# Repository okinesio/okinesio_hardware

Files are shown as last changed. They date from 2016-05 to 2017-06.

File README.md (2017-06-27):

# okinesio | Hardware files

This repository contains resources for the okinesio boards.

Head over to [okinesio.org/hardware](http://okinesio.org/hardware) for an overview.

License Information
-------------------
The hardware designs are released under [CC-SA v3 license](http://creativecommons.org/licenses/by-sa/3.0).

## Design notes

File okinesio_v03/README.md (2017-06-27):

# okinesio v0.3

The latest version with completely new layout. Featuring an on-board lipo charger and lipo connector which replaces the coin cell.
With the BMM150 (magnetometer) the board is adding up to 9-DOF and there is a microSD card reader on the backside.

```
Size:    approx. 30 x 20 mm

Operating Voltage:     3.3V
Input Voltage:         3-5V
Clock Speed:           8MHz

Microcontroller: ATmega32U4
Flash:                32 KB
SRAM:                2.5 KB
EEPROM:                1 KB
```

Eagle files and schematics are modified and extended versions of the original files from [LilyPad Arduino USB](https://github.com/sparkfun/LilyPad_Arduino_USB).

License Information
-------------------
The hardware design is released under [CC-SA v3 license](http://creativecommons.org/licenses/by-sa/3.0).

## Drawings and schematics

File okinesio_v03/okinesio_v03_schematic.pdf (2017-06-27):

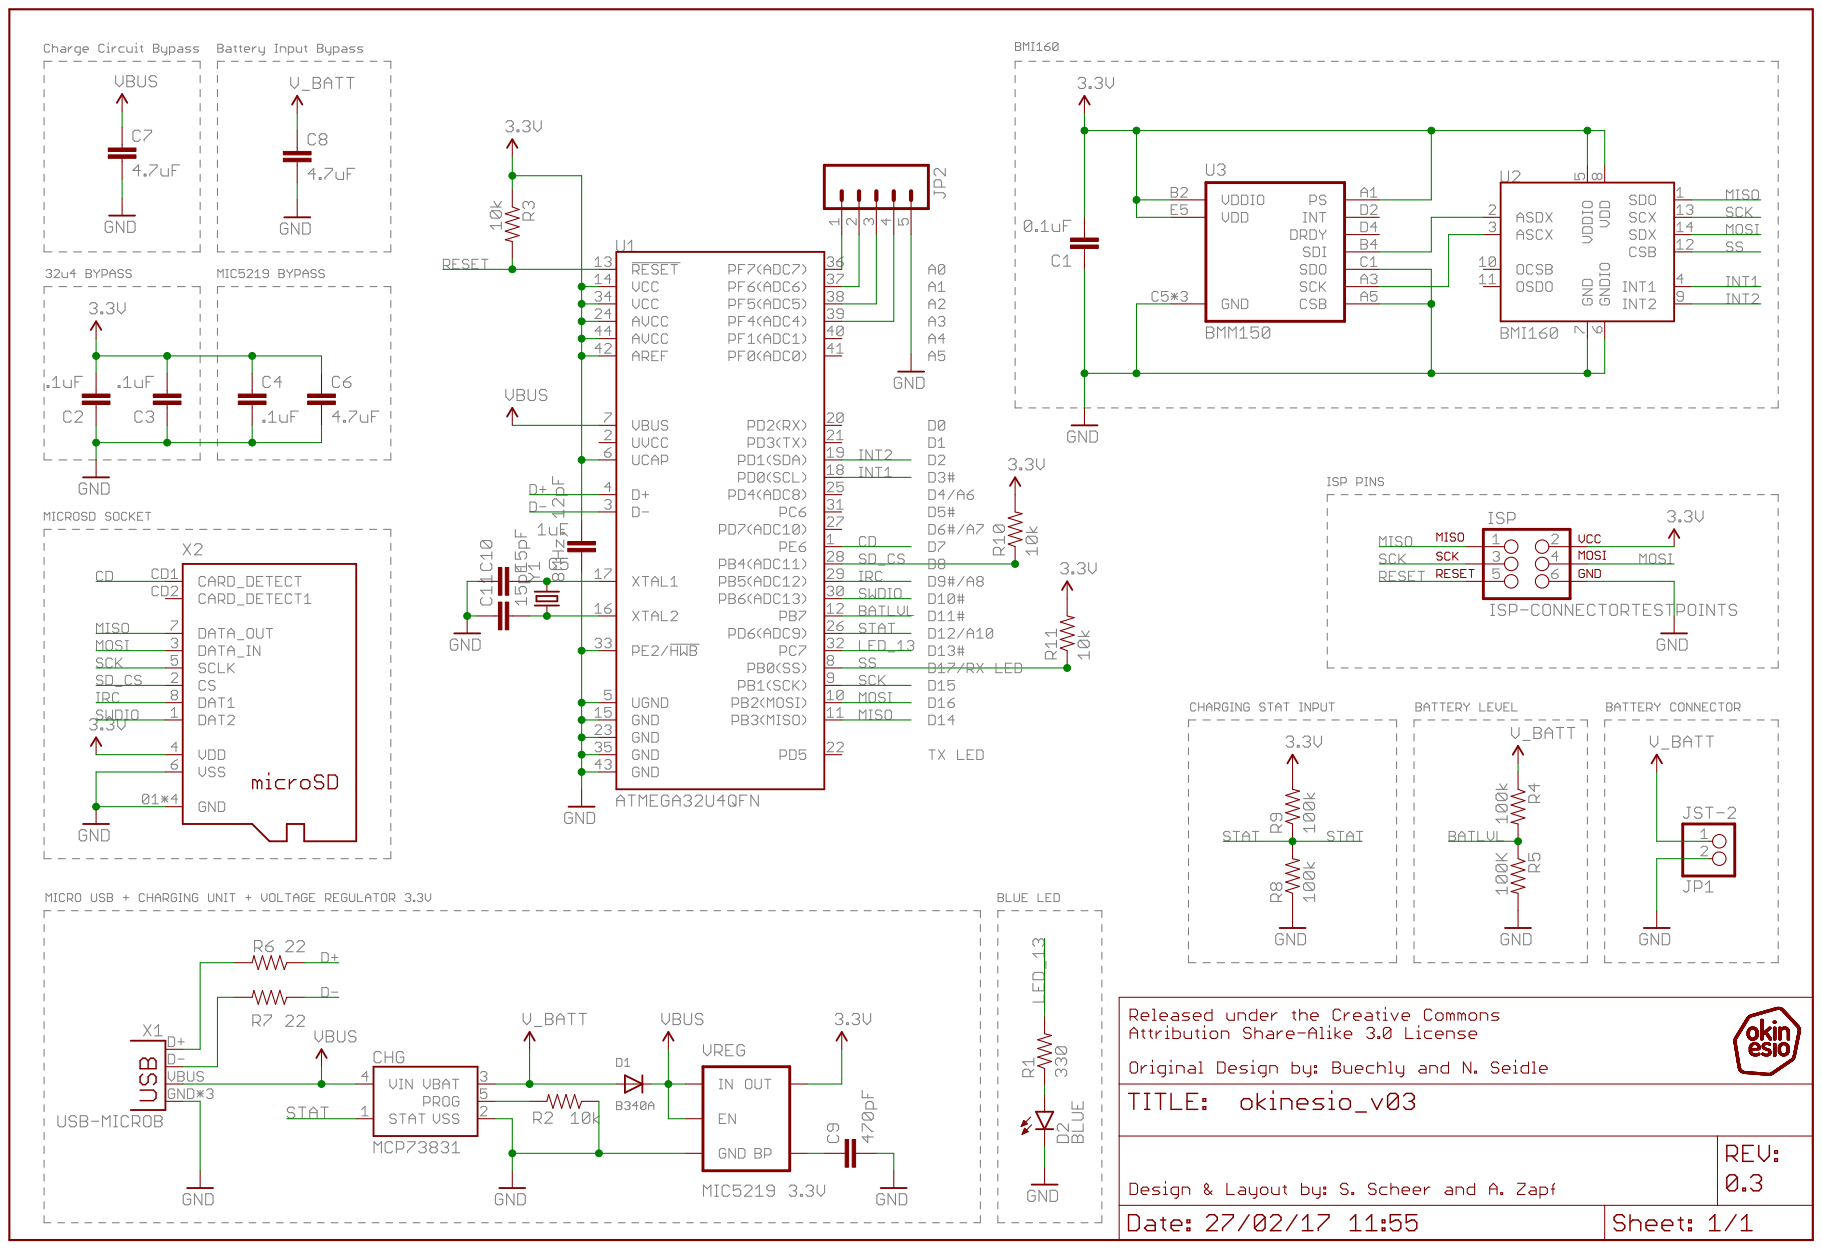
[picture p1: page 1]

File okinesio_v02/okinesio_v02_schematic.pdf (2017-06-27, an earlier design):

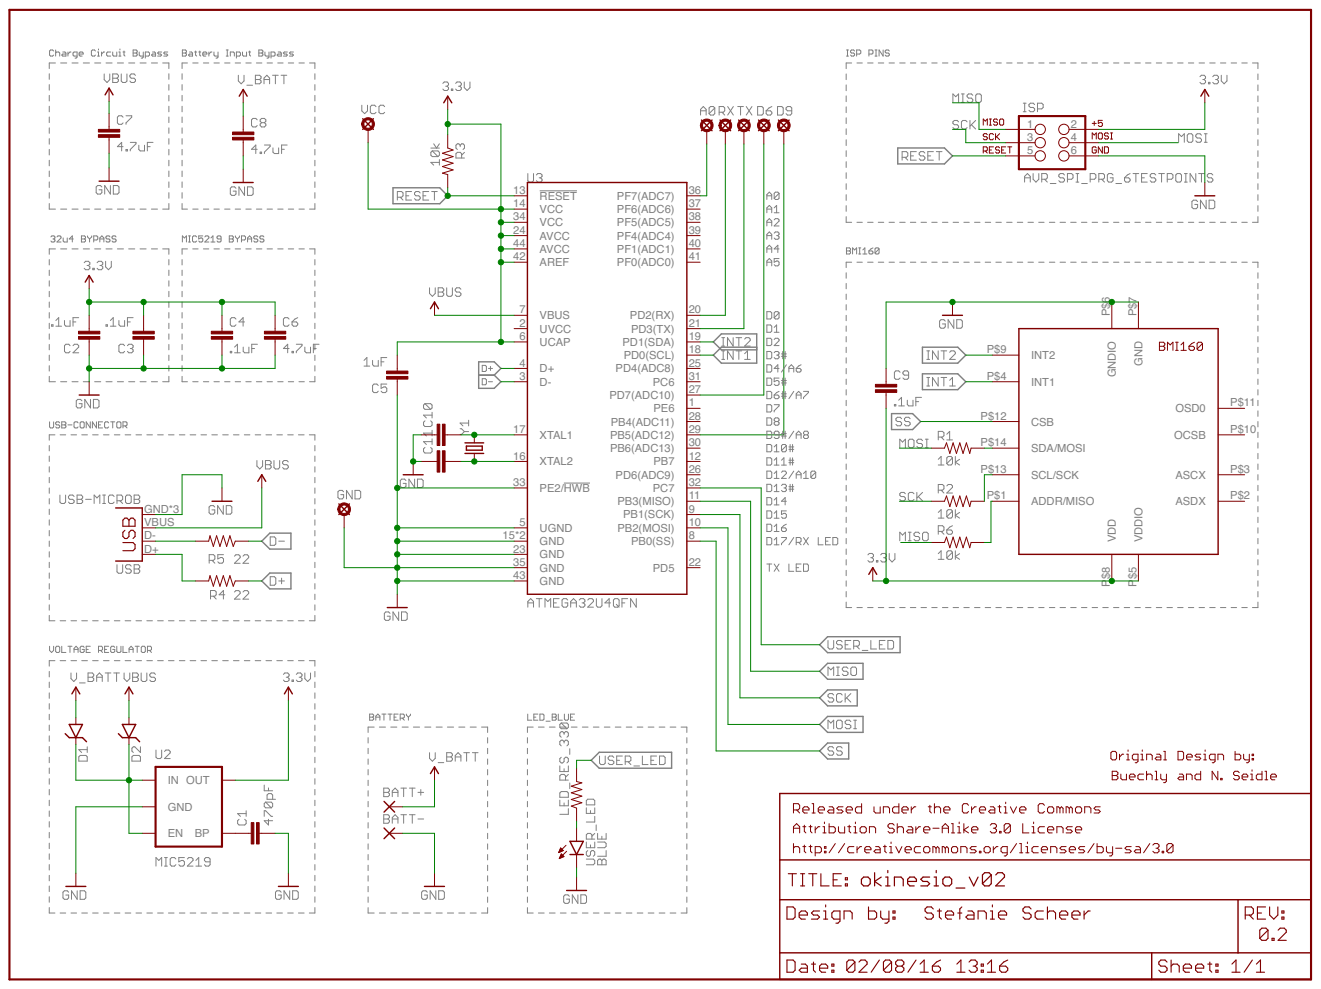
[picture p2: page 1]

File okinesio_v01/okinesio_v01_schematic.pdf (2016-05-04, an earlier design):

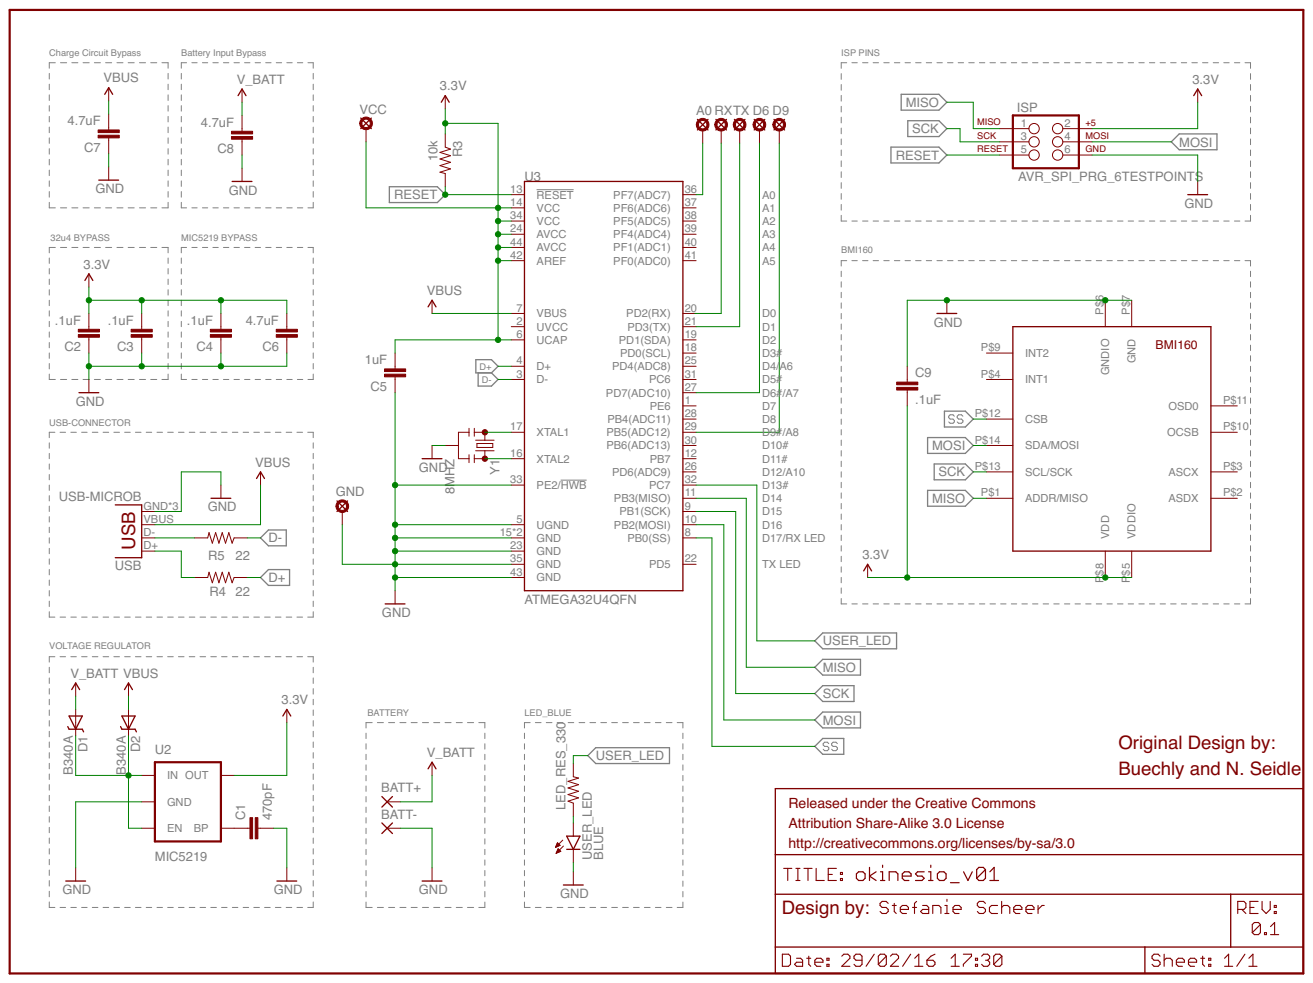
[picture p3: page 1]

Released under the Creative Commons Attribution Share-Alike 3.0 License

http://creativecommons.org/licenses/by-sa/3.0

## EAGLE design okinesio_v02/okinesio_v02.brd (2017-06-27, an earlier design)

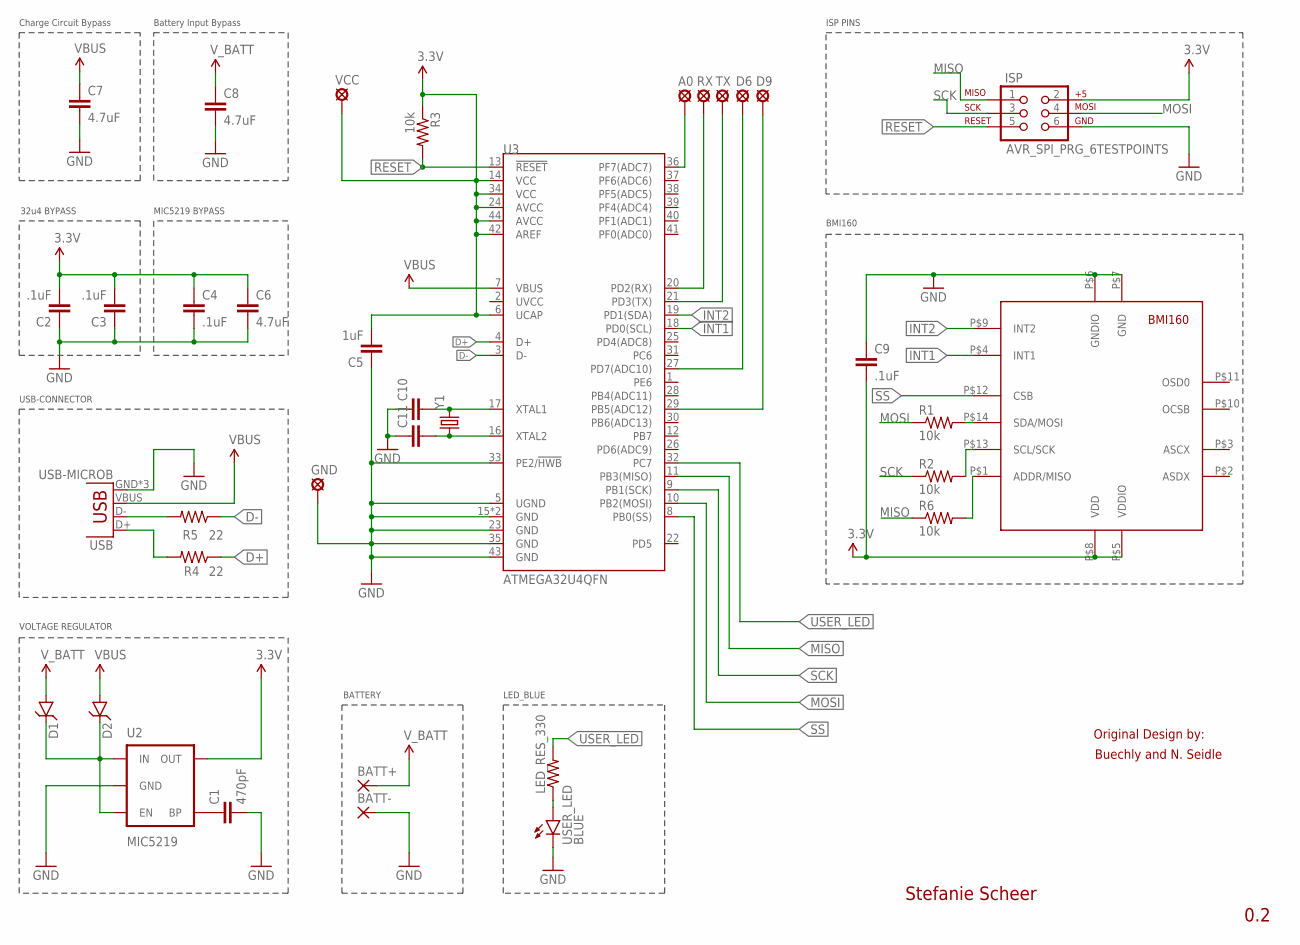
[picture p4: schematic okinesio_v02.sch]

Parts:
A0: LSP10
BATT+: SMD2; SMD1,27-2,54
BATT-: SMD2; SMD1,27-2,54
C1: 470pF; 0603-CAP
C2, C3, C4, C9: .1uF; 0603-CAP
C5: 1uF; 0603-CAP
C6: 4.7uF; 0603-CAP
C7, C8: 4.7uF; 0805
C10, C11: CAP0603-CAP; 0603-CAP
D1, D2: DIODESOD123; SOD-123
D6, D9: LSP10
GND: LSP10
ISP: AVR_SPI_PRG_6TESTPOINTS; 2X3_TEST_POINTS
LED_RES_330: RESISTOR0603; 0603-RES
R1, R2, R3, R6: 10k; 0603-RES
R4, R5: 22; 0603-RES
RX: LSP10
TX: LSP10
U2: MIC5219; SOT23-5
U3: ATMEGA32U4QFN; QFN-44
U$3: BMI160LGA14; LGA14-BMI160
USB: USB-MICROB
USER_LED: BLUE; LED-0603
VCC: LSP10
Y1: CRYSTALTXC-7A; CRYSTAL-TXC-7A

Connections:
3.3V: C2.2, C3.2, C4.1, C5.2, C6.1, C9.2, ISP.2, R3.1, U2.5 (OUT), U3.6 (UCAP), U3.14 (VCC), U3.24 (AVCC), U3.34 (VCC), U3.42 (AREF), U3.44 (AVCC), U$3.P$5 (VDDIO), U$3.P$8 (VDD), VCC.MP
5V: C7.1, D2.A, U3.7 (VBUS), USB.VBUS
D+: R4.1, U3.4 (D+)
D-: R5.1, U3.3 (D-)
GND: BATT-.1, C1.2, C2.1, C3.1, C4.2, C5.1, C6.2, C7.2, C8.2, C9.1, C10.1, C11.1, GND.MP, ISP.6, U2.2 (GND), U3.5 (UGND), U3.15 (GND), U3.23 (GND), U3.33 (PE2/!HWB), U3.35 (GND), U3.43 (GND), U3.EPAD (GND), U$3.P$6 (GNDIO), U$3.P$7 (GND), USB.GND, USB.MT1 (GND), USB.MT2 (GND), USER_LED.C
INT1: U3.18 (PD0(SCL)), U$3.P$4 (INT1)
INT2: U3.19 (PD1(SDA)), U$3.P$9 (INT2)
MISO: ISP.1, R6.1, U3.11 (PB3(MISO))
MOSI: ISP.4, R1.1, U3.10 (PB2(MOSI))
unnamed: D1.C, D2.C, U2.1 (IN), U2.3 (EN)
unnamed: D6.MP, U3.27 (PD7(ADC10))
unnamed: TX.MP, U3.21 (PD3(TX))
unnamed: A0.MP, U3.36 (PF7(ADC7))
unnamed: C10.2, U3.17 (XTAL1), Y1.P$2 (2)
unnamed: D9.MP, U3.29 (PB5(ADC12))
unnamed: LED_RES_330.1, USER_LED.A
unnamed: C1.1, U2.4 (BP)
unnamed: RX.MP, U3.20 (PD2(RX))
unnamed: R1.2, U$3.P$14 (SDA/MOSI)
unnamed: R5.2, USB.D-
unnamed: R4.2, USB.D+
unnamed: R2.2, U$3.P$13 (SCL/SCK)
unnamed: R6.2, U$3.P$1 (ADDR/MISO)
unnamed: C11.2, U3.16 (XTAL2), Y1.P$1 (1)
RESET: ISP.5, R3.2, U3.13 (!RESET)
SCK: ISP.3, R2.1, U3.9 (PB1(SCK))
SS: U3.8 (PB0(SS)), U$3.P$12 (CSB)
USER_LED: LED_RES_330.2, U3.32 (PC7)
V_BATT: BATT+.1, C8.1, D1.A

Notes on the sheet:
32u4 BYPASS
MIC5219 BYPASS
Charge Circuit Bypass
Battery Input Bypass
Original Design by:
Stefanie Scheer
0.2
Buechly and N. Seidle
USB-CONNECTOR
VOLTAGE REGULATOR
BATTERY
LED_BLUE
ISP PINS
BMI160

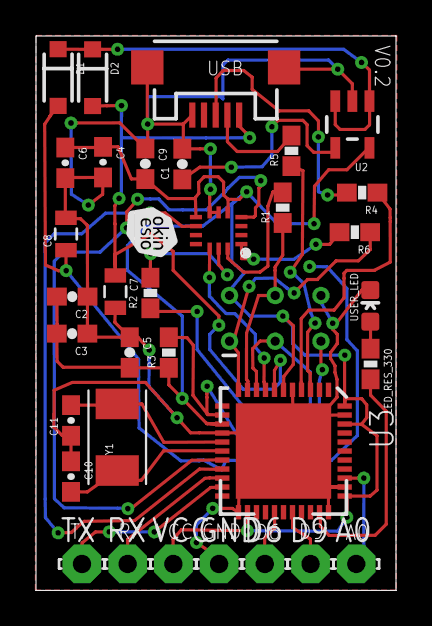
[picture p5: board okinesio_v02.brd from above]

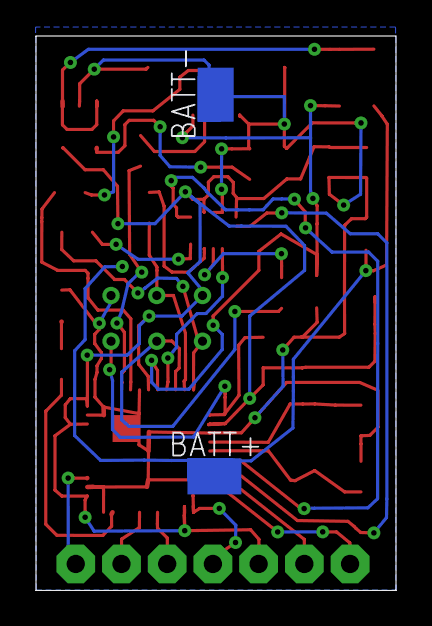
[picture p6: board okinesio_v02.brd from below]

Board: 2 copper layers, 20.0 x 30.8 mm, 36 parts (2 on the bottom side), 29 nets.

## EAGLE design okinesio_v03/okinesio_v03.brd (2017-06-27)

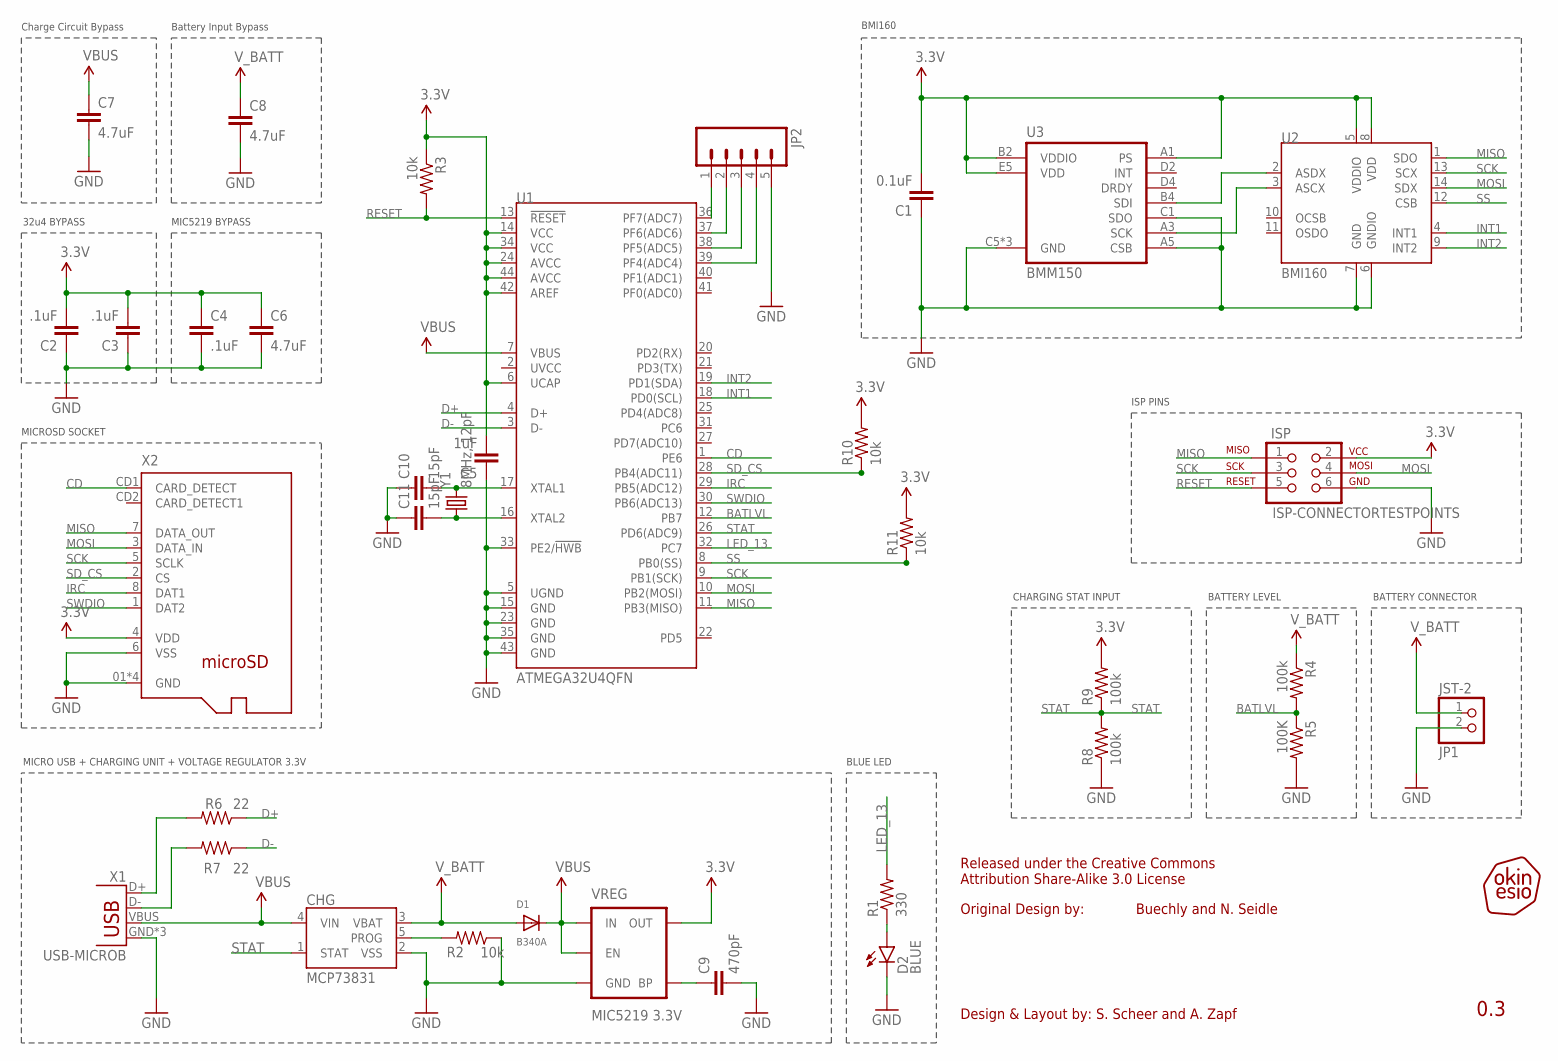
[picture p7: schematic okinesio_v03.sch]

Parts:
C1: 0.1uF; 0603-CAP
C2, C3, C4: .1uF; 0603-CAP
C5: 1uF; 0603-CAP
C6: 4.7uF; 0603-CAP
C7, C8: 4.7uF; 0805
C9: 470pF; 0603-CAP
C10, C11: 15pF; 0603-CAP
CHG: MCP73831; SOT23-5
D1: B340A; SOD-123
D2: BLUE; LED-0603
ISP: ISP-CONNECTORTESTPOINTS; 2X3_TEST_POINTS
JP1: JST-2; JST-PH-2-THM-RA
JP2: M05PTH; 1X05
R1: 330; 0603-RES
R2, R3, R10, R11: 10k; 0603-RES
R4, R8, R9: 100k; 0603-RES
R5: 100K; 0603-RES
R6, R7: 22; 0603-RES
U1: ATMEGA32U4QFN; QFN-44
U2: BMI160LGA14; LGA14-BMI160
U3: BMM150; WLCSP12-1.56X1.56
U$4: OKINESIO-LOGO-2.85X2.81MM; LOGO-STANDARD
VREG: MIC5219 3.3V; SOT23-5
X1: USB-MICROB
X2: MICROSD-SOCKET
Y1: 8MHz, 12pF; CRYSTAL-TXC-7A

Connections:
3.3V: C1.2, C2.2, C3.2, C4.1, C5.2, C6.1, ISP.2, R3.1, R9.2, R10.2, R11.2, U1.6 (UCAP), U1.14 (VCC), U1.24 (AVCC), U1.34 (VCC), U1.42 (AREF), U1.44 (AVCC), U2.5 (VDDIO), U2.8 (VDD), U3.A1 (PS), U3.B2 (VDDIO), U3.E5 (VDD), VREG.5 (OUT), X2.4 (VDD)
5V: C7.1, CHG.4 (VIN), D1.C, U1.7 (VBUS), VREG.1 (IN), VREG.3 (EN), X1.VBUS
BATLVL: R4.2, R5.1, U1.12 (PB7)
CD: U1.1 (PE6), X2.CD1 (CARD_DETECT)
D+: R6.1, U1.4 (D+)
D-: R7.1, U1.3 (D-)
GND: C1.1, C2.1, C3.1, C4.2, C5.1, C6.2, C7.2, C8.2, C9.2, C10.1, C11.1, CHG.2 (VSS), D2.C, ISP.6, JP1.2 (1), JP2.5, R2.1, R5.2, R8.1, U1.5 (UGND), U1.15 (GND), U1.23 (GND), U1.33 (PE2/!HWB), U1.35 (GND), U1.43 (GND), U2.6 (GNDIO), U2.7 (GND), U3.A5 (CSB), U3.C1 (SDO), U3.C5 (GND), U3.E1 (GND), U3.E3 (GND), VREG.2 (GND), X1.GND, X1.MT1 (GND), X1.MT2 (GND), X2.01 (GND), X2.02 (GND), X2.03 (GND), X2.04 (GND), X2.6 (VSS)
INT1: U1.18 (PD0(SCL)), U2.4 (INT1)
INT2: U1.19 (PD1(SDA)), U2.9 (INT2)
IRC: U1.29 (PB5(ADC12)), X2.8 (DAT1)
LED_13: R1.2, U1.32 (PC7)
MISO: ISP.1, U1.11 (PB3(MISO)), U2.1 (SDO), X2.7 (DATA_OUT)
MOSI: ISP.4, U1.10 (PB2(MOSI)), U2.14 (SDX), X2.3 (DATA_IN)
unnamed: U2.2 (ASDX), U3.B4 (SDI)
unnamed: JP2.1, U1.36 (PF7(ADC7))
unnamed: JP2.2, U1.37 (PF6(ADC6))
unnamed: JP2.3, U1.38 (PF5(ADC5))
unnamed: C10.2, U1.17 (XTAL1), Y1.P$2 (2)
unnamed: JP2.4, U1.39 (PF4(ADC4))
unnamed: D2.A, R1.1
unnamed: U2.3 (ASCX), U3.A3 (SCK)
unnamed: CHG.5 (PROG), R2.2
unnamed: C9.1, VREG.4 (BP)
unnamed: C11.2, U1.16 (XTAL2), Y1.P$1 (1)
unnamed: R7.2, X1.D-
unnamed: R6.2, X1.D+
RESET: ISP.5, R3.2, U1.13 (!RESET)
SCK: ISP.3, U1.9 (PB1(SCK)), U2.13 (SCX), X2.5 (SCLK)
SD_CS: R10.1, U1.28 (PB4(ADC11)), X2.2 (CS)
SS: R11.1, U1.8 (PB0(SS)), U2.12 (CSB)
STAT: CHG.1 (STAT), R8.2, R9.1, U1.26 (PD6(ADC9))
SWDIO: U1.30 (PB6(ADC13)), X2.1 (DAT2)
V_BATT: C8.1, CHG.3 (VBAT), D1.A, JP1.1 (2), R4.1

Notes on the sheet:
32u4 BYPASS
MIC5219 BYPASS
Charge Circuit Bypass
Battery Input Bypass
Original Design by:
Buechly and N. Seidle
BATTERY CONNECTOR
BLUE LED
BMI160
MICRO USB + CHARGING UNIT + VOLTAGE REGULATOR 3.3V
BATTERY LEVEL
CHARGING STAT INPUT
MICROSD SOCKET
Released under the Creative Commons Attribution Share-Alike 3.0 License
0.3
Design & Layout by: S. Scheer and A. Zapf
ISP PINS

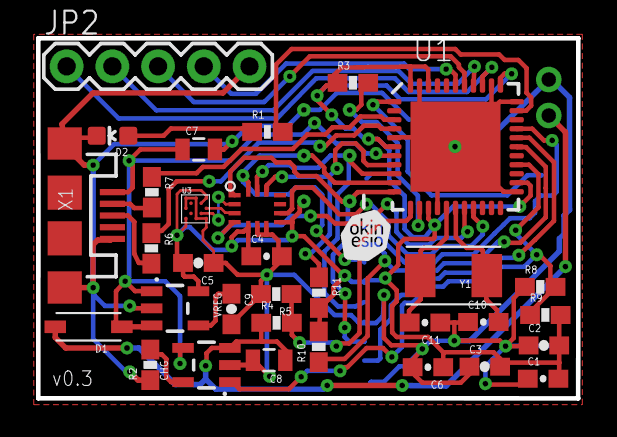
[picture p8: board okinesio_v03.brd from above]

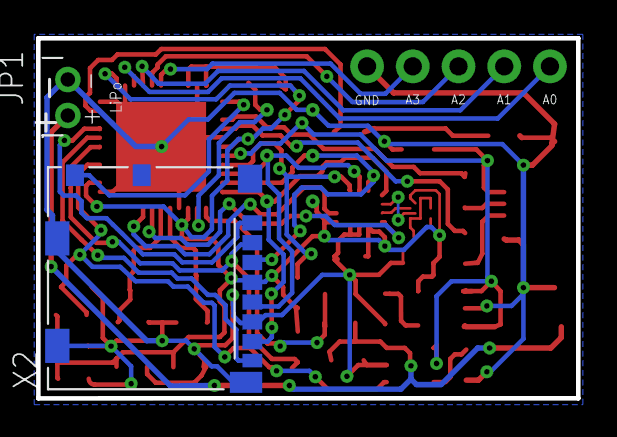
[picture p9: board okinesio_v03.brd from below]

Board: 2 copper layers, 30.0 x 20.0 mm, 36 parts (2 on the bottom side), 33 nets.

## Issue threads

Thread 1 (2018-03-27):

Inconsistent Package

ib0t, 2018-03-27:
In okinesio_v0.3 is the board and the schematic inconsistent because of an inconsistent package of the microcontroller (U1). Perhabs this is because the okinesio.lbr library file is not included in the repository.

ib0t, 2018-03-27:
I have solved this issue and created a pull request with the fix

Closed 2018-03-27.

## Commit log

2016-05-04 added board and schematic files
    [okinesio_v01.brd, okinesio_v01.sch]
2016-05-04 added schematic as PDF
2017-06-27 Added hardware files
    Added files for okinesio v0.2 and v0.3.
    Moved okinesio v0.1 into folder and changed repository name.
    [okinesio_v01.brd, okinesio_v01.sch, okinesio_v02.brd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]

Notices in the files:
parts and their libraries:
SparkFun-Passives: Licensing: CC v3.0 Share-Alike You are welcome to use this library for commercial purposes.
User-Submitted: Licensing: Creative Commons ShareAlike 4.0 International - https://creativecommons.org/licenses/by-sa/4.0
